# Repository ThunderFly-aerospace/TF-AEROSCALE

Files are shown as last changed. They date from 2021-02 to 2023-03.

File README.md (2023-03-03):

# TF-AEROSCALE
**Force balance for measuring lift and drag of aerodynamic surfaces**

Knowledge of aircraft wings is important for optimizing their flight parameters. This scale-type device is used to measure the polar of the wing or rotor. The device is designed so that it is possible to measure wings/rotors of various sizes. Because it is difficult to obtain a enought large wind tunnel, weight is designed so that it can be operated, for example, on the roof of a [TF-R1 driving car](https://github.com/ThunderFly-aerospace/TF-R1) that ensures suficiently high quality laminar flow.

## Features

* Robust construction to measure Lift and Drag forces up to 400 N.
* Open-source design (Open-source HW and SW)
* Scalability for different needs (OpenSCAD parametric design)
* Polar measurement capable (Lift and drag ratio calculation)
* Airspeed and groundspeed measurement
* RPM measurement (In case of rotor)
* Use on a car roof or in a wind tunnel

## Parameters

| Parameter | Value | Description |
|---|---|---|
| Sensing element | strain gauges |  |
| Interface | USB | The data readout is realised by direct control of I2C devices |
| Operating and storage temperature | -20 - +40°C |  |
| Operational humidity | 0-100 % | At humidity above 80% the performance of the sensors could be degraded in case of prolonged time periods |
| Input power | USB powered | |
| Mass | 5 kg |  |
| Dimensions |  600 x 560 x 600 mm| Height x width x lenght |
| Weather resistance | IP40 | |

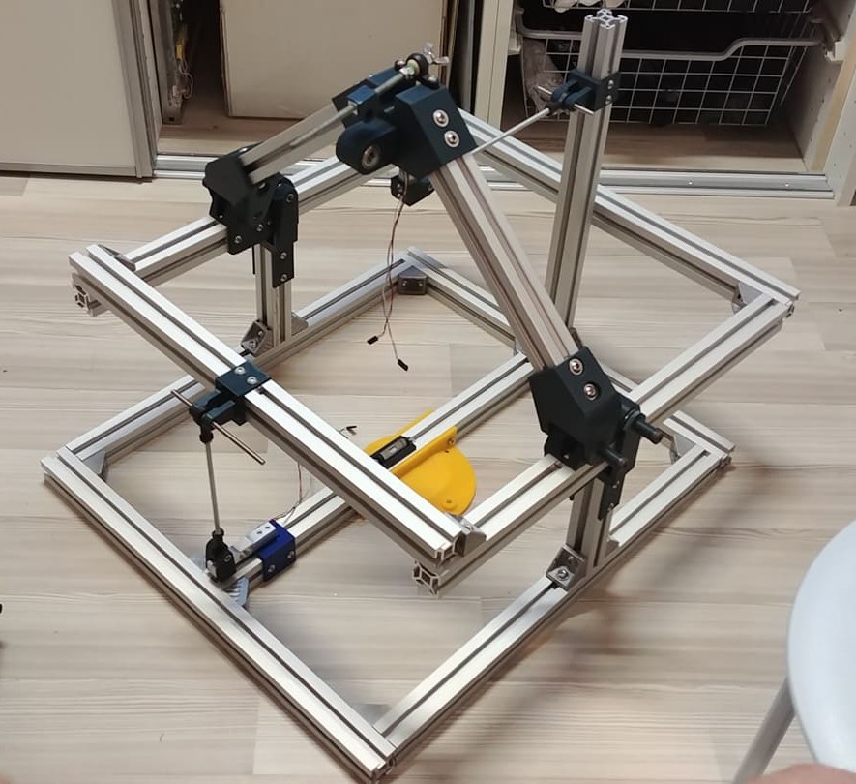
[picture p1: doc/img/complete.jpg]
Base with strain gauges


# Software installation

Repository use git submodules therefore an initialization of repository is needed prior make.

    git submodule init
    git submodule update

After that commands the make should be run from src directory.

    force_balance/cad/src$ make -j 4

## Electrical connection

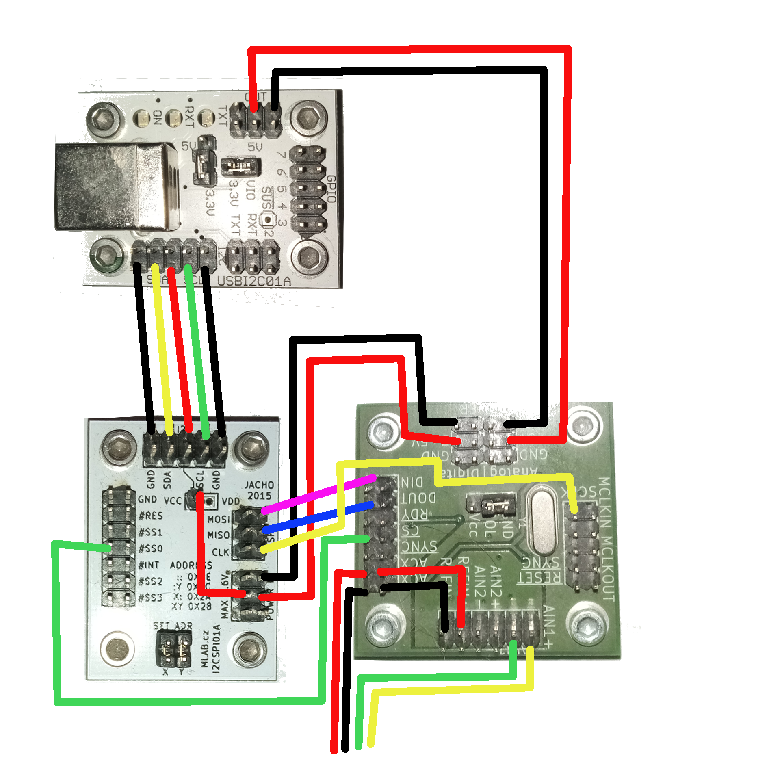
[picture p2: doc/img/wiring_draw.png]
Elecrical connection


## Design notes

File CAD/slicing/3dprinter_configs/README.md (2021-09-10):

# 3dprinter_configs

3D Printer configurations repository 

### Struktura

Ve složce src jsou dílčí zdrojové kódy konfigurací tiskáren. 

Složka `dist/<tiskarna>` obsahuje celkové ini soubory přímo pro užití se slicerem.

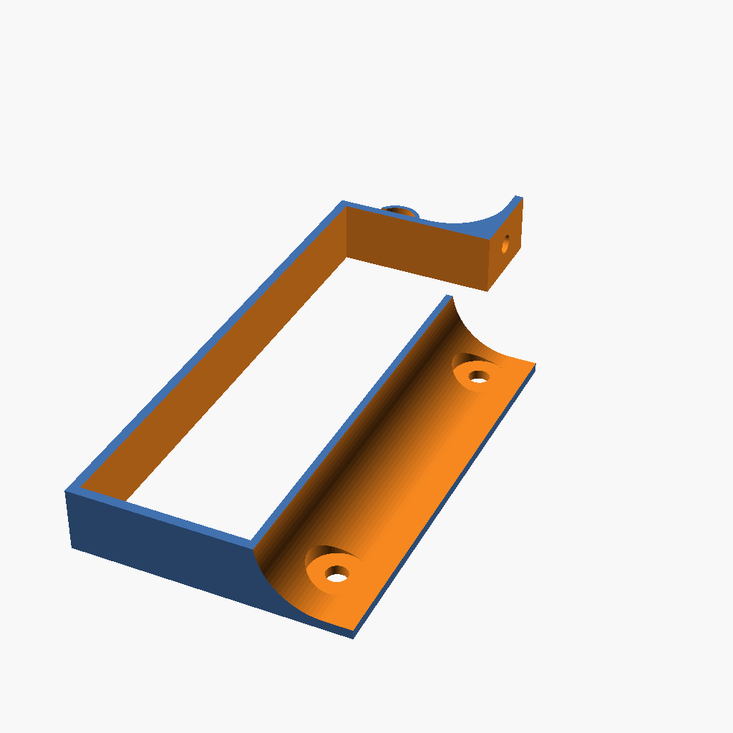
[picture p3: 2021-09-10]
CAD/png/888_5014_Back.png

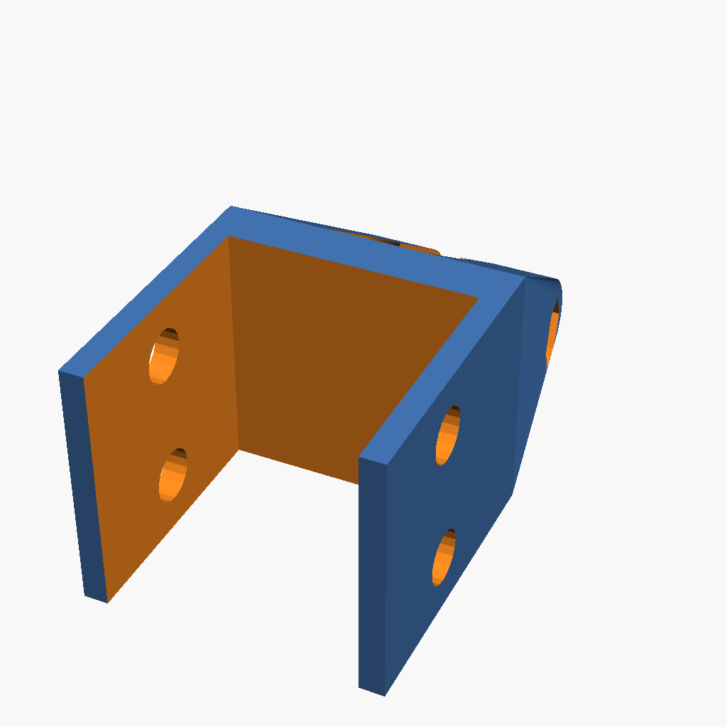
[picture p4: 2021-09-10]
CAD/png/888_5003_A.png

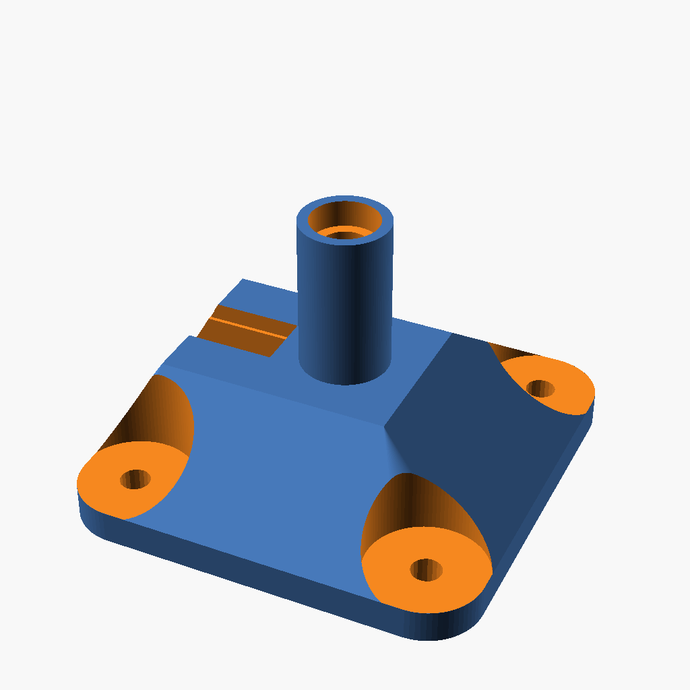
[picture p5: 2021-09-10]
CAD/png/TF_G2_rotor_adapter.png

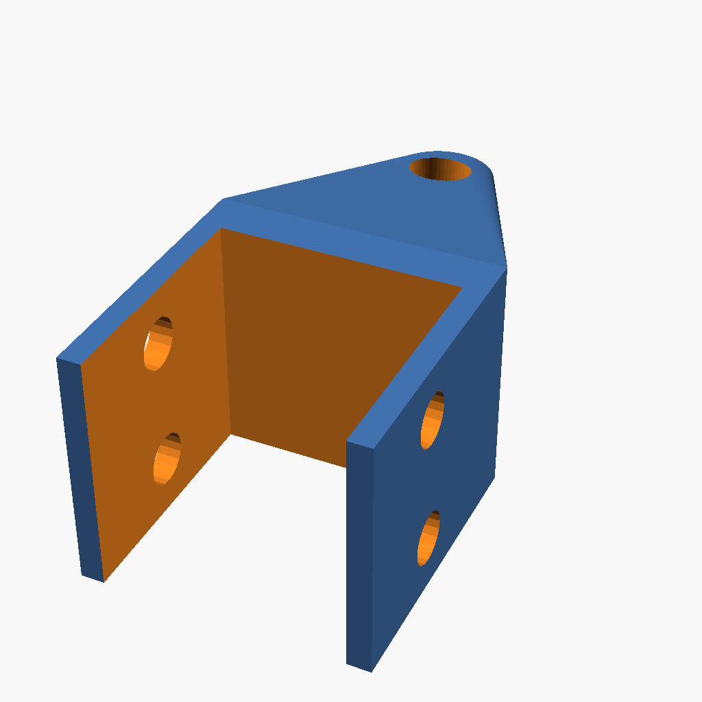
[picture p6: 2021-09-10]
CAD/png/888_5003_B.png

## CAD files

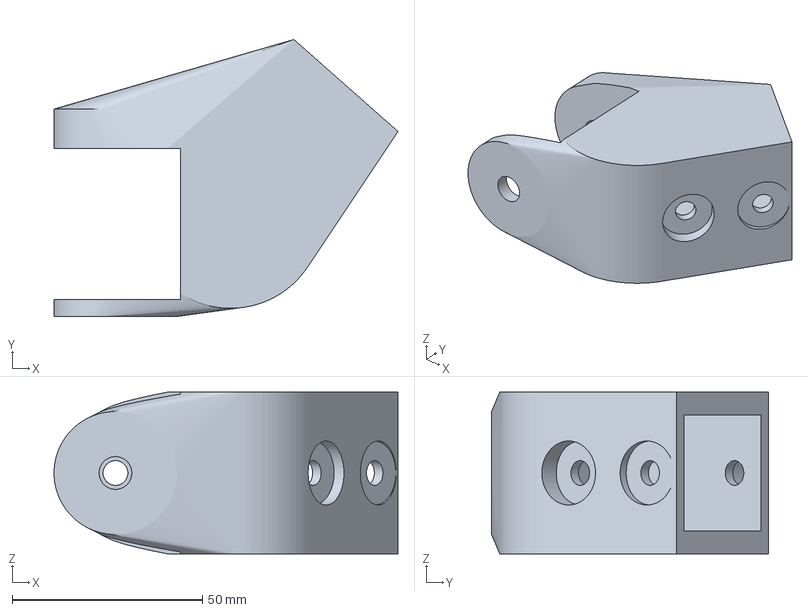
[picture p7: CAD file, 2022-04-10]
CAD/amf/888_5006.amf
90.4 x 72.8 x 42.5 mm

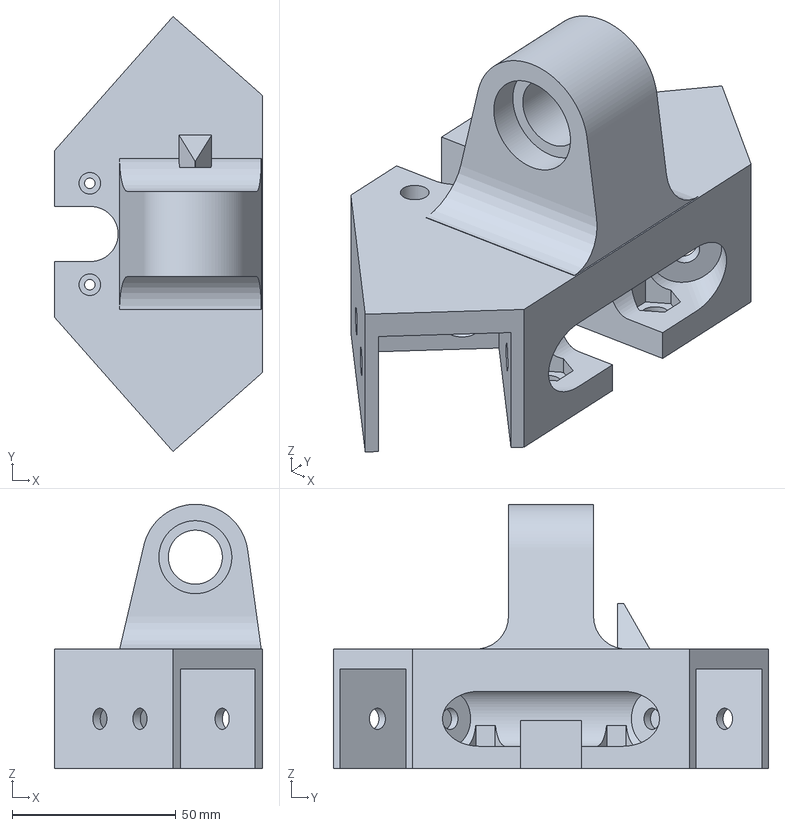
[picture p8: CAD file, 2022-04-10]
CAD/amf/888_5007.amf
63.6 x 132.9 x 80.8 mm

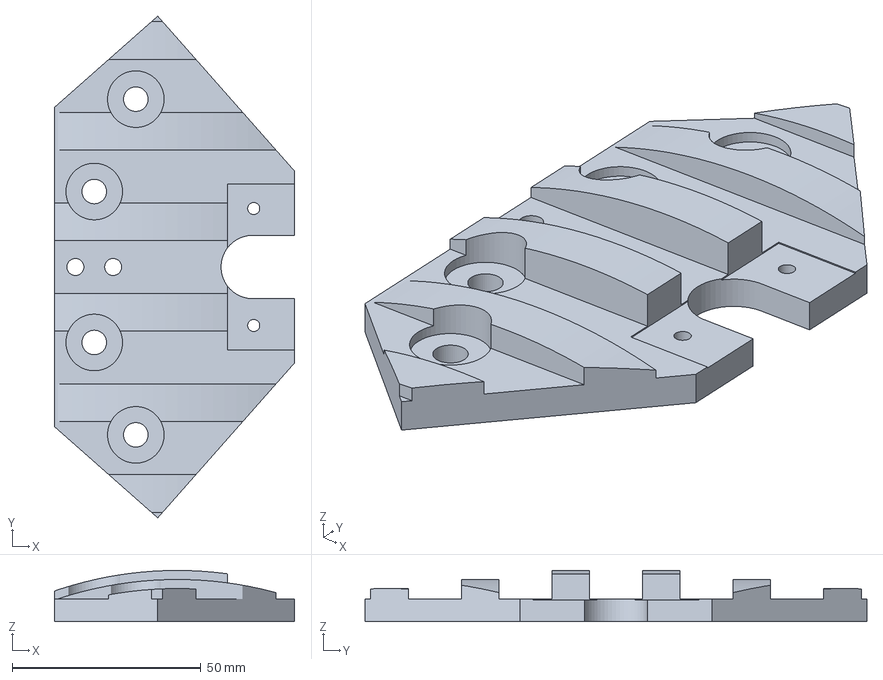
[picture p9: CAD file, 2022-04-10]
CAD/amf/888_5015.amf
63.6 x 132.9 x 13.6 mm

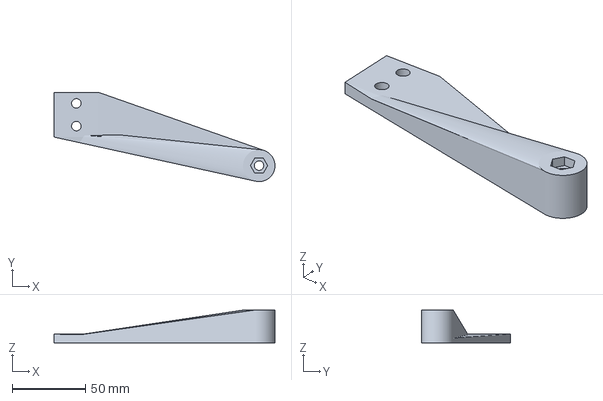
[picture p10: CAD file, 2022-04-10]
CAD/amf/888_1001.amf
150.9 x 60.9 x 22.4 mm

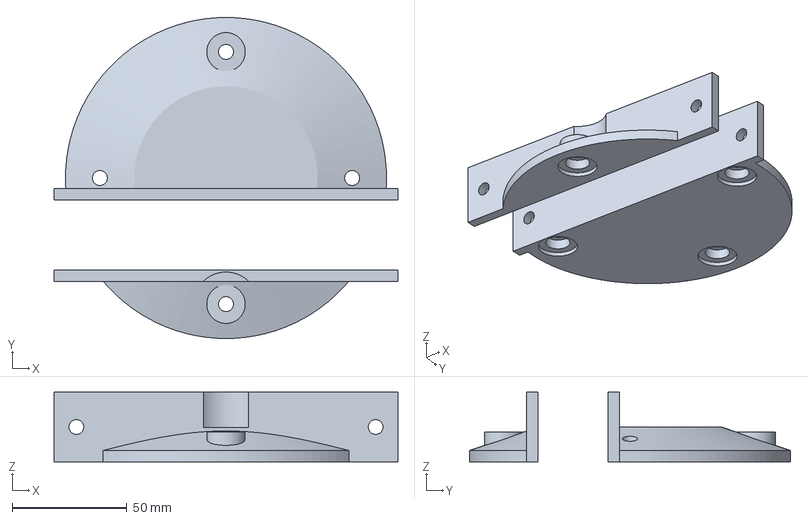
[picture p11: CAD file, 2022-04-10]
CAD/amf/888_3007.amf
150.0 x 140.0 x 30.5 mm

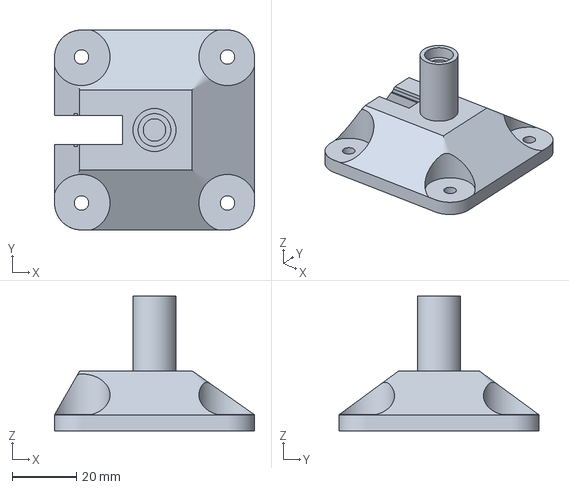
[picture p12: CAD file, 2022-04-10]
CAD/amf/TF_G2_rotor_adapter.amf
62.3 x 62.3 x 41.9 mm

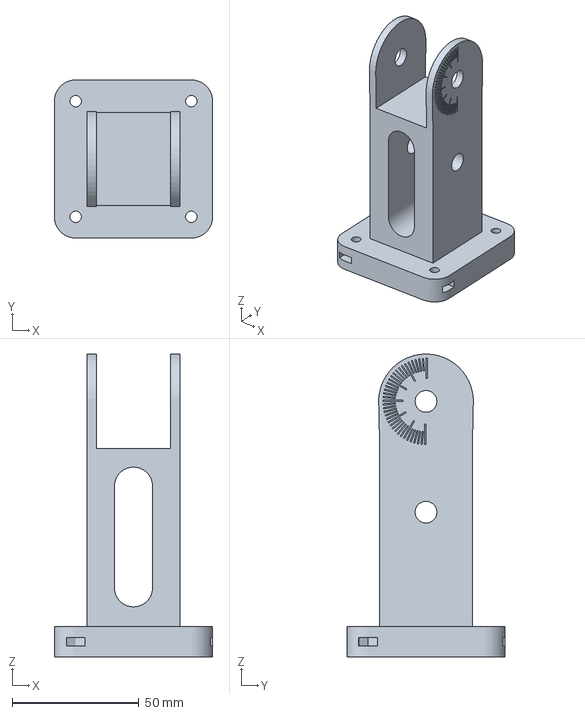
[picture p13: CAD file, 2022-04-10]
CAD/amf/888_5008.amf
62.3 x 62.3 x 119.3 mm

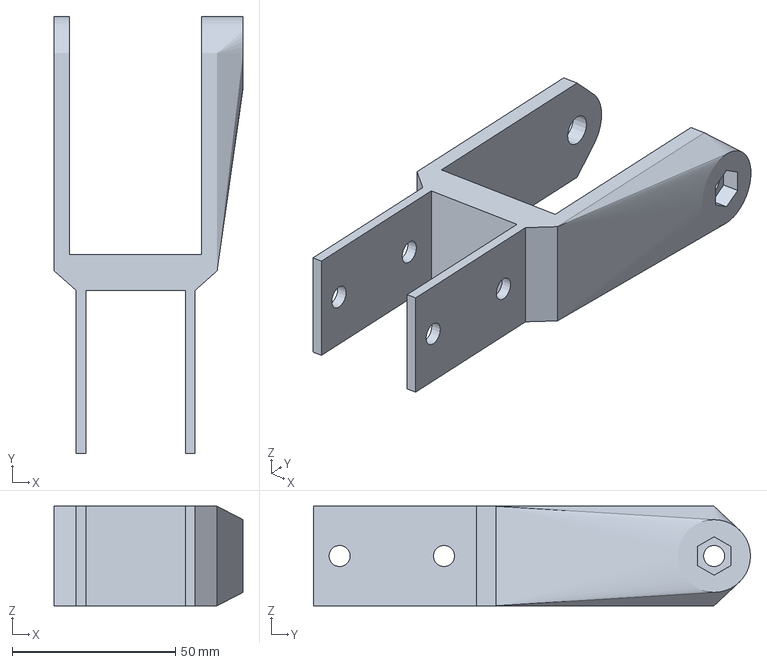
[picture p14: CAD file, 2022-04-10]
CAD/amf/888_5004.amf
57.9 x 133.9 x 30.5 mm

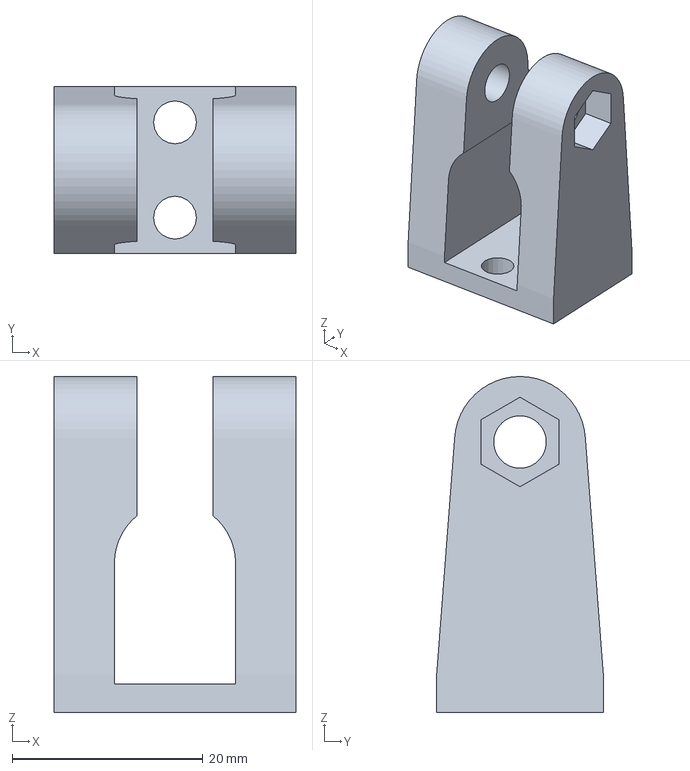
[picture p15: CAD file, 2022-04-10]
CAD/amf/888_5002.amf
25.4 x 17.5 x 35.3 mm

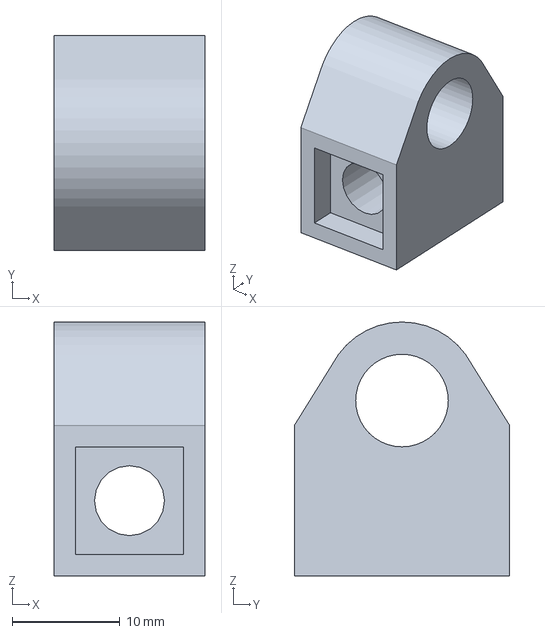
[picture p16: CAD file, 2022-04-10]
CAD/amf/888_5009.amf
14.0 x 20.0 x 23.6 mm

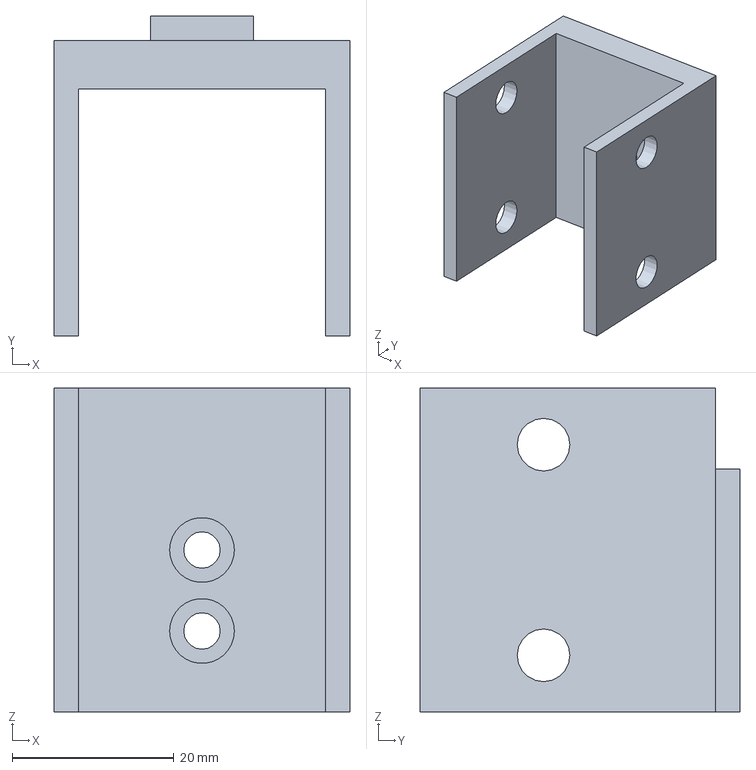
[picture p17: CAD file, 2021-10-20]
CAD/amf/888_5001.amf
36.5 x 39.5 x 40.0 mm

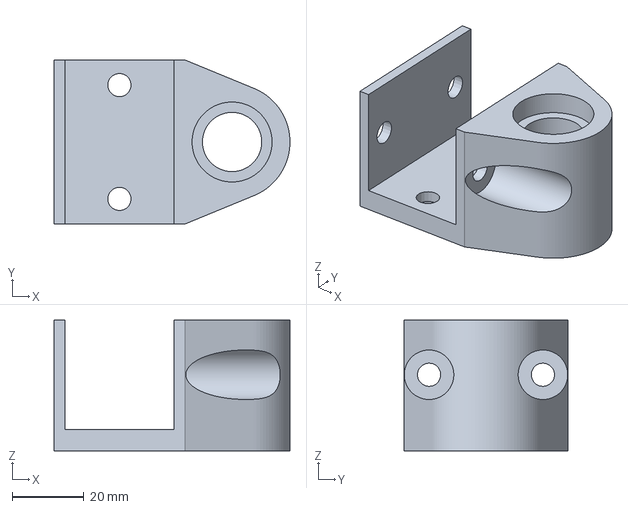
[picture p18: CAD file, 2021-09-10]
CAD/amf/888_5005.amf
65.8 x 45.8 x 36.5 mm

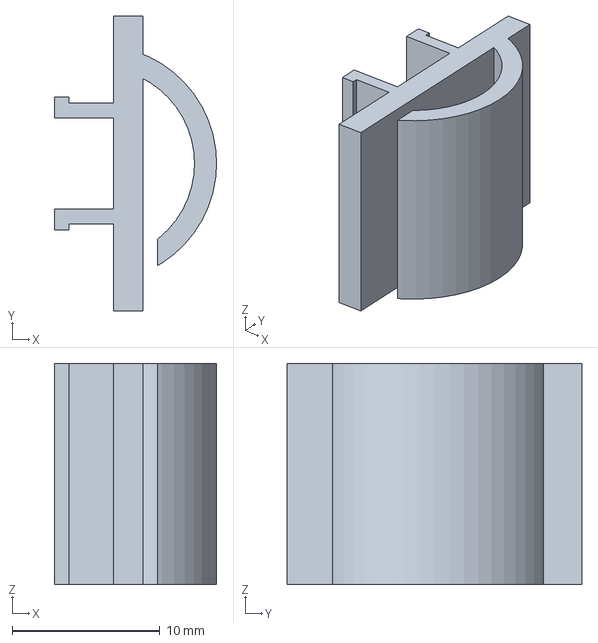
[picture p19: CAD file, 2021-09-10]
CAD/amf/888_5013.amf
11.0 x 20.0 x 15.0 mm

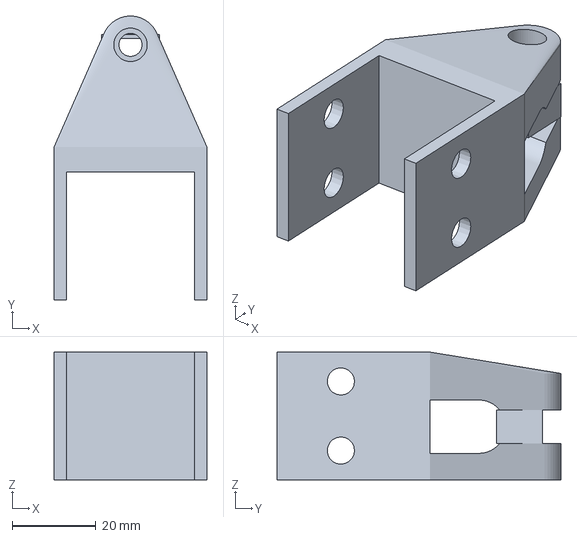
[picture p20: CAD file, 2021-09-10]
CAD/amf/888_5003_B.amf
36.5 x 67.8 x 30.5 mm

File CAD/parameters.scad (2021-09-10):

maximum_printable_size = 150;

layer_thickness = 0.3;
global_clearance = 0.5;


//Screw diameter and nut for M10 [mm]
M10_screw_diameter = 10.4;
M10_head_height = 10;
M10_head_diameter = 16+0.5;
M10_nut_height = 10.5;
M10_nut_diameter = 25.5;
M10_nut_pocket = 22.3;

//Screw diameter for M8 [mm]
M8_screw_diameter = 8.6;
M8_head_height = 8;
M8_head_diameter = 13.5;
M8_nut_height = 7.5;
M8_square_nut_thin_height = 4.5;
M8_nut_diameter = 14.4 + 0.5;
M8_nut_pocket = 13 + 0.5;
M8_washer_diameter = 16;
M8_washer_thickness = 1.5;


//Screw diameter and nut for M6 [mm]
M6_screw_diameter=6.5;
M6_head_diameter = 10+0.5;
M6_head_height = 6;
M6_nut_height = 4.9;
M6_nut_diameter = 11.8;
M6_nut_pocket = 10.4;
M6_square_nut_height = 3;
M6_square_nut_diameter = 10;
M6_washer_thickness = 1.6;

//Screw diameter and nut for M5 [mm]
M5_screw_diameter=5.5;
M5_head_height = 5;
M5_head_diameter = 13+0.5;
M5_nut_height = 4.5;
M5_nut_diameter = 9.4;
M5_nut_pocket = 8.4;

//Screw diameter and nut for M4 [mm]
M4_screw_diameter=4.5;
M4_screw_head_height = 4;
M4_nut_height = 3.2;
M4_nut_diameter = 8.4;
M4_nut_pocket = 7.5;

//Screw diameter and nut for M3 [mm]
M3_screw_diameter = 3.2;
M3_nut_height = 2.7;
M3_nut_diameter = 6.6;
M3_nut_pocket = 5.6;
M3_screw_head_height = 3;

//Screw diameter and nut for M2,5 [mm]
M2_5_screw_diameter = 2.7;
M2_5_nut_height = 2.3;
M2_5_nut_diameter = 6;
M2_5_nut_pocket = 5.5;

// kulove lozisko

bearing_efsm_08_h = 33+1;
bearing_efsm_08_m = 22;
bearing_efsm_08_db = 18;
bearing_efsm_08_ag = 10.5;
bearing_efsm_08_n = M4_screw_diameter;
bearing_efsm_08_a1 = 5.5;
bearing_efsm_08_d = 8.25;
bearing_efsm_08_B = 8; // ball height

bearing_efsm_10_h = 38+1;
bearing_efsm_10_m = 26;
bearing_efsm_10_db = 21.9;
bearing_efsm_10_ag = 12+0.2;
bearing_efsm_10_n = M5_screw_diameter;
bearing_efsm_10_a1 = 6.5;
bearing_efsm_10_d = 10.25;


bearing_efsm_12_width = 40+1;
bearing_efsm_12_h = bearing_efsm_12_width;
bearing_efsm_12_boltd = 28/2; // polovina vzdalenosti mezi srouby
bearing_efsm_12_m = bearing_efsm_12_boltd*2;
bearing_efsm_12_db = 25;
bearing_efsm_12_ag = 13;
bearing_efsm_12_a1 = 7;
bearing_efsm_12_n = M5_screw_diameter;
bearing_efsm_12_d = 12.15;
bearing_efsm_12_B = 10; // ball height
bearing_efsm_space = 1;

bearing_efsm_17_width = 54+1;
bearing_efsm_17_h = bearing_efsm_17_width;
bearing_efsm_17_boltd = 38/2; // polovina vzdalenosti mezi srouby
bearing_efsm_17_m = bearing_efsm_17_boltd*2;
bearing_efsm_17_db = 35;
bearing_efsm_17_ag = 18;
bearing_efsm_17_n = M6_screw_diameter;
bearing_efsm_17_a1 = 10;
bearing_efsm_17_B = 17; // ball height

//limcove lozisko
bearing_EFOM_10_L=26; //celkova sirka zakladny
bearing_EFOM_10_d1=10.3;//diametr otvoru real=10 mm
bearing_EFOM_10_dB=22;//diametr vystupku pro ulozeni lozika
bearing_EFOM_10_H=52;//celková delka zakladny
bearing_EFOM_10_J=36;// hole pitch
bearing_EFOM_10_A1=6.5;//vyska pouzdra
bearing_EFOM_10_Ag=12;//celkova vyska
bearing_EFOM_10_N1=5;//sirka otvoru pro sroub
bearing_EFOM_10_N2=8;//delka otvoru pro sroub
bearing_EFOM_10_m=36;//roztec der pro sroub
bearing_EFOM_10_h=9;//vyska lozika


608_bearing_outer_diameter = 22.3;
608_bearing_inner_diameter = 16;
608_bearing_thickness = 7.1;


// 20 KG servo parameters

servo_20kg_axis_offset = 9.375; // jak je osa mimo stredu
servo_20kg_body_x = 42;
servo_20kg_body_y = 21;
servo_20kg_body_z = 40;
servo_20kg_thread_x = 49/2;
servo_20kg_thread_y = 10/2;
servo_20kg_body_below = 10; // jak hluboko je tělo serva pod drzaky na srouby
servo_20kg_below = 25.8; // jak hluboko je páka serva pod drzaky na srouby

servo_20kg_bolt_d = 2.5+0.3;
servo_20kg_nut_d = 5+0.3;


//strain gauge
strain_gauge_width = 12.7;
strain_gauge_length = 75.1;
strain_gauge_screw_distance = 10;

//ALU profile
ALU_profile_width = 30.5;
ALU_profile_holder_wall_thickness = 3;
ALU_profile_groove_width = 8;

//pillow block bearing
//https://www.igus.eu/product/372
//Part no. KSTM-08
KSTM08_screws_distance = 33;         //m
KSTM08_screws_holes_diameter = 4.5;  //d2
KSTM08_flange_thickness = 6;         //h3
KSTM08_case_width = 9;               //C1
KSTM08_case_length = 47;             //a
KSTM08_ball_width = 12;              //B
KSTM08_ball_hole_diameter = 7.85;    //d1


//ložiska pro malý rotor
bearing_outer_diameter = 10.2;    // Rozměr B1 v nákresu s přídavkem na toleranci otvoru
bearing_thickness = 4;        // Rozměr B2 v nákresu
//bearing_shaft_length = 19.5;    // Rozměr B3 v nákresu, Originalni hodnota 19.5
bearing_shaft_length = 20;    // Rozměr B3 v nákresu


//parametry víčka s telemetrickou anténou
S01_sila_materialu=1.2;
S01_vyska_horni_zavit=10;
S01_hloubka_zavitu=4;
S01_prumer_vnitrni=50;
LO_spodni_prumer=17.2;
LO_vyska_bez_krytu=15;
S01_tolerance_zavit=1.5;
R01_vyska_prekryti_statoru=10;

g3_0_cone1 = 70;
g3_0_srcew_dist = 55;



// scale parameters
base_length = 500;
mid_base_width = 500;
mid_base_height = 200;
mid_base_length = 500;
mid_base_x_offset = 50;
base_mid_base_hinge_offset = 50;
tower_height = 185;
tower_angle = atan((mid_base_width/2-ALU_profile_width-10)/tower_height);
tower_arm_length = tower_height/cos(tower_angle);
tower_drag_z_offset = 22;
electro_box_length = 225;
electro_box_width = 165;
electro_box_height = 51.5;

// calibration device parameters
calibration_arm_x_offset = 140;
calibration_arm_y_offset = 50;

// rotor paramters
rotor_blades_count = 2;
rotor_delta_angle = 12;
blade_mount_screw = M3_screw_diameter;
blade_mount_nut = M3_nut_diameter;

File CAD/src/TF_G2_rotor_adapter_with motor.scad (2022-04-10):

include <../parameters.scad>

use <./TF-G2-rotor-neck.scad>

$fn = 100;


connector_hole_w=45;
connector_hole_d=4.2;
connector_h=5;

connector_top_w=25;
connector_top_h=6;



TFPROBE01_PCB_thickness = 1.8;
TFPROBE01_PCB_width = 10.2;
TFPROBE01_sensor_height = 1.1;


motor_distance = -78.8; // vzdalenost prerotatoru od hlavni pos_y
motor_diameter = 35+2;
motor_axis_diameter = 6.3;
motor_puller_diameter = 20;
motor_screw_diameter = M3_screw_diameter;
motor_mounting_diameter = 25; // vzdalenost protejsich sroubu pro pridelani prerotatoru
motor_sink = 9.5+4+1; // pro zapusteni bez podlozek na motoru...


screw_offset=rotorBearingNeck_screw_offset();
screw_angle=rotorBearingNeck_screw_angle();

module TF_G2_rotor_adapter(){

    difference()
    {
        union()
        {        
            hull()
            {

                //podstava
                minkowski()
                {
                    translate([0,0,connector_h/2-motor_sink])
                        cube([connector_hole_w,connector_hole_w,0.001],center=true);
                    cylinder(d=16,h=connector_h,center=true);
                }                 
                
                //zamek
                translate([0,0,-connector_top_h/2])
                    cube([connector_top_w,connector_top_w,connector_top_h],center=true);
                
                //motor
                translate([0,motor_distance,-motor_sink/2])
                    cylinder(d=motor_diameter,h=motor_sink,center=true);
                    
                //rpm
                translate([0,5+rotorBearingNeck_t()/2+2,-TFPROBE01_sensor_height-TFPROBE01_PCB_thickness/2])
                   cube([TFPROBE01_PCB_width+2,10,TFPROBE01_PCB_thickness+2], center=true);
            }
        }
        
        //zámek krčku
        rotorBearingNeckHousing();
       
        //šrouby motoru        
        translate([0,motor_distance,0])
            rotate([0,0,45])
            {
                cylinder(d=motor_puller_diameter, h=5*motor_sink,center=true);
                for(i=[-1,1])
                    translate([i*motor_mounting_diameter/2,0,0])
                    {
                       cylinder(d=motor_screw_diameter,h=5*motor_sink,center=true);
                       translate([0,0,-3])
                            cylinder(d=5.5,h=3.01);
                    }
                for(i=[-1,1])
                    translate([0,i*motor_mounting_diameter/2,0])
                    {
                       cylinder(d=motor_screw_diameter,h=5*motor_sink,center=true);
                       translate([0,0,-3])
                            cylinder(d=5.5,h=3.01);
                    }
            }
        
        //odlehčení
        hull()
        {
            translate([0,-30,0])
                cylinder(d=22,h=5*motor_sink, center=true);
                
            translate([0,-62,0])
                cube([28,1,5*motor_sink], center=true);
        
        }
        
        //rpm senzor
        translate([0,50/2+rotorBearingNeck_t()/2-2,-2.5*motor_sink-TFPROBE01_sensor_height])
           cube([TFPROBE01_PCB_width-2,50,5*motor_sink], center=true);
        translate([0,50/2+rotorBearingNeck_t()/2-2,+2.5*motor_sink-TFPROBE01_sensor_height+0.2])
           cube([TFPROBE01_PCB_width-2,50,5*motor_sink], center=true);
        translate([0,50/2+rotorBearingNeck_t()/2-2,-TFPROBE01_sensor_height-TFPROBE01_PCB_thickness/2])
           cube([TFPROBE01_PCB_width,50,TFPROBE01_PCB_thickness], center=true);
        
        //šrouby
        for(i=[-1,1])
            for(j=[-1,1])
            {
                translate([i*connector_hole_w/2,j*connector_hole_w/2,0])
                {
                    cylinder(d=connector_hole_d,h=5*motor_sink,center=true);
                    translate([0,0,-motor_sink+connector_h])
                        cylinder(d=16,h=5*motor_sink);
                }
            }
            
            
        //matice    
        for(i=[-1,1])  
        translate([i*(screw_offset),-screw_offset,0])
            rotate([screw_angle,0,0])
                translate([0,0,-7-M3_nut_height])
                hull()
                {
                    cylinder(d=M3_nut_pocket+0.9,h=M3_nut_height+0.1, $fn=6);
                    translate([i*50,0,0])
                        cylinder(d=M3_nut_pocket+0.9,h=M3_nut_height+0.1, $fn=6);
                }
        //díra pro štělování ložiska
        cylinder(d=3.5,h=50, center=true);
    }
    
    //vyztuha na vršku matice
    for(i=[-1,1])  
    translate([i*(screw_offset),-screw_offset,0])
        rotate([screw_angle,0,0])
            translate([0,0,-7+0.1])
                cylinder(d=7,h=0.2, $fn=6);

    
    
}


TF_G2_rotor_adapter();

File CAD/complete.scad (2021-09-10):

include <./parameters.scad>
use <./src/lib/ALU_profile.scad>
use <./src/888_3007.scad>
use <./src/888_5001.scad>
use <./src/888_5002.scad>
use <./src/888_5003.scad>
use <./src/888_5004.scad>
use <./src/888_5005.scad>
use <./src/888_5006.scad>
use <./src/888_5007.scad>
use <./src/888_5008.scad>
use <./src/888_5009.scad>
use <./src/888_5010.scad>
use <./src/888_5011.scad>
use <./src/888_5012.scad>
use <./src/888_5013.scad>
use <./src/888_5014.scad>
use <./src/888_5015.scad>
use <./src/888_1001.scad>
use <./src/888_1002.scad>
use <./src/888_1003.scad>


base_width = mid_base_width+ALU_profile_width*2+ALU_profile_holder_wall_thickness*2+M6_washer_thickness*2;
side_pillars_offset = -ALU_profile_width/2+base_mid_base_hinge_offset;
mid_base_height_offset = (608_bearing_outer_diameter+10)/2-1;

module tenzometer(mounting_part=true) {
    translate([-strain_gauge_length/2, -strain_gauge_width/2, 0])
    color([0, 0, 1])
    cube([strain_gauge_length, strain_gauge_width, strain_gauge_width]);
    
    if(mounting_part) {
        translate([-7.5, ALU_profile_width/2+ALU_profile_holder_wall_thickness, -ALU_profile_holder_wall_thickness])
        rotate([90, 0 ,-90])
        color([0, 1, 1])
        888_5001();
    }
    
    translate([strain_gauge_length/2-(strain_gauge_screw_distance*1.75)/2, 0, 0])
    rotate([0, 0 ,90])
    color([0, 1, 1])
    888_5002();
}


// base ///////////////////////////////////////////////////////////////
translate([-base_length/2, 0, ALU_profile_width/2])
rotate([0, 90, 0])
ALU_profile(height=base_length);

translate([-base_length/2, base_width/2-ALU_profile_width*2+ALU_profile_holder_wall_thickness+5, ALU_profile_width/2])
rotate([0, 90, 0])
ALU_profile(height=base_length);

translate([-base_length/2, -base_width/2+ALU_profile_width*2-ALU_profile_holder_wall_thickness-5, ALU_profile_width/2])
rotate([0, 90, 0])
ALU_profile(height=base_length);

translate([-base_length/2-ALU_profile_width/2, -base_length/2, ALU_profile_width/2])
rotate([0, 90, 90])
ALU_profile(height=base_length);

translate([base_length/2+ALU_profile_width/2, -base_length/2, ALU_profile_width/2])
rotate([0, 90, 90])
ALU_profile(height=base_length);

translate([mid_base_length/2-mid_base_x_offset+2, 0, ALU_profile_width+ALU_profile_holder_wall_thickness*3])
tenzometer();

// car attachment point
translate([0, 24.8, 0])
rotate([0, 0, 0])
color([0, 1, 1])
888_3007();

//box
translate([mid_base_length/2, -base_length/2+3, ALU_profile_width])
rotate([0, 0, 180])
color([0, 1, 1])
888_5014_back();

translate([mid_base_length/2-150, -base_length/2+3, ALU_profile_width])
rotate([0, 0, 180])
color([0, 1, 1])
888_5014_front();

translate([mid_base_length/2+ALU_profile_width/2, -base_length/2+3+electro_box_width+ALU_profile_width, ALU_profile_width+3])
rotate([0, 0, 180])
color([0, 1, 1])
#cube([electro_box_length, electro_box_width, electro_box_height]);

// front pillar //////////////////////////////////////////////////////
translate([-base_length/2-ALU_profile_width/2, 0, ALU_profile_width])
ALU_profile(height=mid_base_height+tower_height+20);

translate([-base_length/2+ALU_profile_holder_wall_thickness*2, -ALU_profile_width/2-ALU_profile_holder_wall_thickness, tower_height-strain_gauge_length/2-tower_drag_z_offset/2+2+mid_base_height+ALU_profile_width*2+ALU_profile_holder_wall_thickness*2-strain_gauge_length/2+(strain_gauge_screw_distance*1.75)/2+M5_screw_diameter*2.5/2])
rotate([180, 0, 90])
color([0, 1, 1])
888_5003_A();


// side pillars ///////////////////////////////////////////////////////
translate([-side_pillars_offset-ALU_profile_width/2, -base_width/2+ALU_profile_width*2-ALU_profile_holder_wall_thickness-5, ALU_profile_width])
ALU_profile(height=mid_base_height+mid_base_height_offset-ALU_profile_width*2-ALU_profile_holder_wall_thickness*4);

translate([-side_pillars_offset-ALU_profile_width/2, base_width/2-ALU_profile_width*2+ALU_profile_holder_wall_thickness+5, ALU_profile_width])
ALU_profile(height=mid_base_height+mid_base_height_offset-ALU_profile_width*2-ALU_profile_holder_wall_thickness*4);

// mid base hinges - static attachment points
translate([-side_pillars_offset, base_width/2-ALU_profile_width*2+ALU_profile_holder_wall_thickness+5, mid_base_height-mid_base_height_offset])
rotate([90, 0, -90])
color([0, 1, 1])
888_5004();

translate([-side_pillars_offset-ALU_profile_width, -base_width/2+ALU_profile_width*2-ALU_profile_holder_wall_thickness-5, mid_base_height-mid_base_height_offset])
rotate([90, 0 ,90])
color([0, 1, 1])
888_5004();

// mid base ///////////////////////////////////////////////////////////
translate([-mid_base_length/2-mid_base_x_offset, mid_base_width/2-ALU_profile_width/2, ALU_profile_width/2+mid_base_height])
rotate([0, 90, 0])
ALU_profile(height=mid_base_length);

translate([-mid_base_length/2-mid_base_x_offset, -mid_base_width/2+ALU_profile_width/2, ALU_profile_width/2+mid_base_height])
rotate([0, 90, 0])
ALU_profile(height=mid_base_length);

translate([-mid_base_length/2-ALU_profile_width/2-mid_base_x_offset, -mid_base_width/2, ALU_profile_width/2+mid_base_height])
rotate([0, 90, 90])
ALU_profile(height=mid_base_width);

translate([mid_base_length/2-ALU_profile_width/2-mid_base_x_offset, -mid_base_width/2, ALU_profile_width*1.5+mid_base_height])
rotate([0, 90, 90])
ALU_profile(height=mid_base_width);

// lift strain gauge attachment point    
translate([mid_base_length/2+ALU_profile_holder_wall_thickness*2-mid_base_x_offset, -ALU_profile_width/2+strain_gauge_width, mid_base_height-ALU_profile_holder_wall_thickness+ALU_profile_width])
rotate([-90, -90 ,0])
color([0, 1, 1])
888_5003_B();
    
// base hinges
translate([ALU_profile_width*.75-base_mid_base_hinge_offset, -mid_base_width/2+ALU_profile_width+ALU_profile_holder_wall_thickness*2, mid_base_height-ALU_profile_holder_wall_thickness])
rotate([0, -90 ,0])
color([0, 1, 1])
888_5005();
    
translate([-ALU_profile_width*.75-base_mid_base_hinge_offset, mid_base_width/2-ALU_profile_width-ALU_profile_holder_wall_thickness*2, mid_base_height-ALU_profile_holder_wall_thickness])
rotate([0, -90, 180])
color([0, 1, 1])
888_5005();

// tower hinges attachment points
translate([ALU_profile_width*.75, -mid_base_width/2+ALU_profile_width+ALU_profile_holder_wall_thickness*2, mid_base_height-ALU_profile_holder_wall_thickness])
rotate([0, -90 ,0])
color([0, 1, 1])
888_5005();
    
translate([-ALU_profile_width*.75, mid_base_width/2-ALU_profile_width-ALU_profile_holder_wall_thickness*2, mid_base_height-ALU_profile_holder_wall_thickness])
rotate([0, -90, 180])
color([0, 1, 1])
888_5005();


// tower ///////////////////////////////////////////////////////////////////
translate([0, mid_base_width/2-ALU_profile_width, ALU_profile_width+mid_base_height+35])
rotate([tower_angle, 0 ,0])
translate([0, ALU_profile_width/2 ,0])
ALU_profile(height=tower_arm_length);

translate([0, -mid_base_width/2+ALU_profile_width, ALU_profile_width+mid_base_height+35])
rotate([-tower_angle, 0 ,0])
translate([0, -ALU_profile_width/2 ,0])
ALU_profile(height=tower_arm_length);

// tower hinges
translate([0, 0, ALU_profile_width+mid_base_height])
color([0, 1, 1])
888_5006(side=-1);
    
translate([0, 0, ALU_profile_width+mid_base_height])
color([0, 1, 1])
888_5006(side=1);

// rotor joint mekanism
translate([0, 0, ALU_profile_width+mid_base_height+35])
rotate([0, 0, 0])
color([0, 1, 1])
888_5007();

translate([0, 0, ALU_profile_width+mid_base_height+35])
rotate([0, 0, 0])
color([0, 1, 1])
888_5015();
    
translate([(608_bearing_outer_diameter+10+ALU_profile_width)/2+ALU_profile_holder_wall_thickness+15, 0, 70+(608_bearing_outer_diameter+10+5)/2+tower_height+mid_base_height+35+ALU_profile_width-12])
rotate([180, 0, 90])
color([0, 1, 1])
888_5008(); 

translate([(608_bearing_outer_diameter+10+ALU_profile_width)/2+ALU_profile_holder_wall_thickness+5, -M6_square_nut_diameter/2-1, 70+(608_bearing_outer_diameter+10+5)/2+tower_height+mid_base_height+ALU_profile_width-6])
rotate([180, 0, 90])
color([0, 1, 1])
888_5009();

// drag strain gauge attachment point
translate([-ALU_profile_width/2-ALU_profile_holder_wall_thickness*2+strain_gauge_width+6, 0, tower_height-strain_gauge_length/2-tower_drag_z_offset/2+2+mid_base_height+ALU_profile_width*2+ALU_profile_holder_wall_thickness*2])
rotate([0, 90, 180])
tenzometer(mounting_part=false);

// calibration device
translate([-base_length/2, -ALU_profile_width/2, mid_base_height+tower_height+20])
rotate([0, 0, 180])
color([1, 1, 0])
union() {
    888_1001();
    
    translate([calibration_arm_x_offset, -.5, calibration_arm_y_offset])
    rotate([90, 0, 0])
    888_1002();
}

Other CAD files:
CAD/amf/888_5014_Front.amf
CAD/amf/888_5012.amf
CAD/amf/888_5014_Back.amf
CAD/amf/888_5010.amf
CAD/print_plates/888_1001.scad
CAD/amf/888_1002.amf
CAD/amf/888_1003.amf
CAD/amf/888_5003_A.amf
CAD/amf/888_5011.amf
CAD/print_plates/888_1002.scad
CAD/print_plates/888_1003.scad
CAD/print_plates/888_3007.scad
CAD/print_plates/888_5001.scad
CAD/print_plates/888_5002.scad
CAD/print_plates/888_5003_A.scad
CAD/print_plates/888_5003_B.scad
CAD/print_plates/888_5004.scad
CAD/print_plates/888_5005.scad
CAD/print_plates/888_5006.scad
CAD/print_plates/888_5007.scad
CAD/print_plates/888_5008.scad
CAD/print_plates/888_5009.scad
CAD/print_plates/888_5010.scad
CAD/print_plates/888_5011.scad
CAD/print_plates/888_5012.scad
CAD/print_plates/888_5013.scad
CAD/print_plates/888_5014_Back.scad
CAD/print_plates/888_5014_Front.scad
CAD/print_plates/888_5015.scad
CAD/print_plates/TF_G2_rotor_adapter.scad
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

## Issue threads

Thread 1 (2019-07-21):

Délky a tolerance šroubů

kaklik, 2019-07-21:
Je potřeba zkontrolovat, zda všechny použité šrouby jsou sehnatelné (tj, mají potřebný rozměr v násobku 5mm)

kaklik, 2019-08-19:
Tenhle problém se momentálně týká zřejmě jen nejdelšího šroubu kyvného spoje.  Kde by spoj chtělo rozšířit tak, aby využíval celou délku 70mm šroubu a unesl tak i větší rotor.

kaklik, 2021-03-07:
Toto issue se s novou konstrukcí stalo irelevantním.

Closed 2021-03-07.

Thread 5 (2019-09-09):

Do základny vytvořit otvor pro matky a podložky šroubů

roman-dvorak, 2019-09-09:
- [x] Vytvořit díry na podložku a matku
- [x] Umístit váhu excentricky

**1**
Do dílu 888_3007 udělat okolo děr pro šrouby pro připevnění na střechu otvor pro zapuštění matic, kterými jsou šrouby permanentně připevněny ke střeše.

https://github.com/ThunderFly-aerospace/force_balance/blob/master/cad/STL/888_3007.stl

Nejlépe to vyřešit stejně jako je to tady:
https://github.com/ThunderFly-aerospace/TF-R1/blob/master/CAD/STL/888_4004.stl
Odtud lze opsat rozměr podložky a celkové velikosti otvoru.

**2**
Další věc, co mne napadá je, umístit váhu mírně excentricky a využít i přední a zadní šroub. Při přemontovávání plaformy zabere docela dost času tyto dva šrouby vytočit. Už jen z důvodu, že je pro to potřeba nějaký nástroj - klíč.

Váhu by stačilo umístít o šířku hliníkových dílů na jednu stranu.

kaklik, 2019-09-30:
V otvorech pouze chybí zaslepené vyrstvy umožňující tisk mostu a tím kvalitnější a pevnější výtisk.

Closed 2019-09-29.

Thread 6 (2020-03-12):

chyba v návrhu dílu 888_5008

kaklik, 2020-03-12:
Následující díl při otevření v openscadu hlásí chybu "UI-WARNING: Object may not be a valid 2-manifold and may need repair! "
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

V důsledku toho vyrenderovaný objekt nelze kompletně vyslicovat jak z STL, tak ani z AMF

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

Closed 2021-02-28.

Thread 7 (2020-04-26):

Měření otáček rotoru během testu

kaklik, 2020-04-26:
Při měření rotoru na aerodynamické váze je potřeba měřit otáčky.

Měření otáček by bylo možné realizovat několika způsoby:

 * ~~hacknutím/rozluštěním komunikace [HiTec senzoru](https://hitecrcd.com/products/aircraft-radios-receivers-and-accessories/telemetry-systems-components/telemetry-components-/hts-orpm-optical-rpm-sensor/product) vyzkoušeno v [repozitáři orpm](https://github.com/ThunderFly-aerospace/orpm)~~
 * ~~Doplněním optického kotoučku a optozávory a použitím snímače [TFRPM01](https://github.com/ThunderFly-aerospace/TFRPM01)~~
 * ~~Přidáním magnetu a hallovy sondy v kombinaci s [TFRPM01](https://github.com/ThunderFly-aerospace/TFRPM01)~~
 * Montáží [TFPROBE](https://github.com/ThunderFly-aerospace/TFPROBE01) a připojením na [RTC03A](https://github.com/MLAB-project/Modules/tree/master/clock/RTC03A)

taury55, 2021-03-08:
Po debatě s @roman-dvorak jsem vyrozuměl, že měření otáček se bude zaznamenávat stejným způsobem jako během letu a měření proto bude součástí rotorové konstrukce a není potřeba jej přidávat do konstrukce váhy.

Data ze senzoru bude zaznaménavát hardware a software váhy nebo se pro to bude využívat některé externí zařízení?

kaklik, 2021-03-08:
Domnívám se že snímač otáček bude v aktuální implementaci realizovaný TFRPM senzorem připojeným na stejnou sběrnici I2C, jako budou připojené tenzometry.
Celkově by tak celé zařízení mělo momentálně končit jedním USB kabelem do palubního počítače v autě.
Je tedy pravda, že z hlediska váhy to příliš speciální úpravy nevyžaduje. Jen je potřeba [držák rotoru](https://github.com/ThunderFly-aerospace/force_balance/blob/master/cad/STL/888_5009.stl). Upravit tak, aby do něj šel vložit snímač [TFPROBE](https://github.com/ThunderFly-aerospace/TFPROBE01).  Podobně, jako je to vyřešené na [rotorové hlavě TF-G2](https://github.com/ThunderFly-aerospace/TF-G2/blob/4s/CAD/stl/printplate_888_1012.stl), kde je snímač [TFPROBE zasunut do drážky z boku](https://github.com/ThunderFly-aerospace/TF-G2/issues/64#issuecomment-761890227).

kaklik, 2021-04-27:
Současné měření s použitím TFPROBE a TFRPM v principu funguje. Jen je potřeba doladit mechanické nedokonalosti adaptéru rotoru a vylepšit kabeláž.
Vítek nakonec chce používat TFSLOT připojený do TFRPM, čímž se využije průchozí I2C sběrnice na TFRPM.

Closed 2021-04-27.

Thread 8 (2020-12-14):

Zjistit, jestli existuje example v Arduinu

roman-dvorak, 2020-12-14:
Bylo by dobré zjistit, jestli dneska existuje nějaký dostupný (arduino) example pro vyčítání převodníku, který obsahuje i interní kalibraci obvodem [AD7730l](https://www.analog.com/media/en/technical-documentation/data-sheets/AD7730_7730L.pdf)

Jedno z možných řešení je k ADpřevodníku připojit k arduino. Další možnost je přečíst si tento kód a implementovat to do pymlabu.

kaklik, 2021-03-07:
Vzhledem k aktuálnímu SW pokroku, který provedl @slimonslimon se toto issue stává irelevantním.

Closed 2021-03-07.

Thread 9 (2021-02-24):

Mechanical strengthening of the aerodynamic force balance

roman-dvorak, 2021-02-24:
Aktuální konstrukce váhy je velmi měkká. Má výrazné vůle do stran, což může způsobovat problémy nejen při měření. Váhu by bylo potřeba rozšířit tak, aby z této "2D" konstrukce se stala třírozměrná konstrukce, která bude v bočním směru pevná. Většina aktuálních dílů je moc pružná. Pokud budou znovu využity některé díly (např. držák tenzometru) tak by měl být zesílen.

Můj návrh je tedy následovný:
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

Díky tomu, že to není plochá konstrukce, tak z toho lze docela těžit u řešení jednotlivých kloubů, kdy se dost rozšiřují možnosti jejich umístění. Nákres není nakreslený v měřítku a jednotlivé délky pák by mělo jít nastavovat. Aktuálně jsou k dispozici dva roměry profilových tyčí (360 mm a 320 mm), které lze používat na první prototpy. Následně pak asi půjde získat jiné délky a tím optimalizovat poměry sil.

Bylo by užitečné aby k tomu existovala celková sestava, kde to bude vidět.

kaklik, 2021-03-07:
@taury55  vytvořil již kompletní celkovou sestavu nové konstrukce:

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

Closed 2021-03-07.

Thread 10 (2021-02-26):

Vibration measurements

roman-dvorak, 2021-02-26:
Bylo by vhodné vybavit vrchní část, kde bude připevňený rotor, měřením vibrací. Pro orientační měření by to mohlo být užitečné.

Toto by se dalo řešit zakomponováním TFSLOT pod rotor, kde by se zároveň s vibracemi měřil airspeed.

kaklik, 2021-02-26:
Nevim jestli je nutný ho připojovat přes SPI, možná by šlo vyčítat jen nějaké maximální a minimální hodnoty. Každopádně je logické ho na SPI připojit, protože tam stejně SPI musí být kvůli těm [BRIDGEADC](https://github.com/mlab-modules/BRIDGEADC01), které se používají pro připojení tenzometrů.

roman-dvorak, 2021-02-26:
Tak o to více by to chtělo získat ten USB-SPI převodník :)

roman-dvorak, 2021-02-26:
Jako extrémní využití tohoto měření bych si dokázal představit nějaké asistované vyvažování rotoru. Něco jako funguje vyvažování kol auta.

kaklik, 2021-02-27:
Jenže k tomu by tam kromě měření otáček muselo být i měření úvratě. Třeba asi tím magnetickým čidlem..
Výhoda by ale byla, že by tím šlo asi oddělit mechanický zdroj vibrací od těch aerodynamických.

roman-dvorak, 2021-02-27:
Připadá mi to jako stejný požadavek na měření polohy rotoru u mlýnku na
elektrické pole.

so 27. 2. 2021 v 12:52 odesílatel Jakub Kákona <notifications@github.com>
napsal:

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

kaklik, 2021-02-27:
Zdá se, že ten snímač, pro který máme v mlabu modul [RPS01A](https://github.com/MLAB-project/Modules/blob/master/sensors/RPS01A/doc/pdf/AS5048_Datasheet_EN_v4.pdf) umí vzorkovat 10kHz. Což by na rotor, který má frekvenci rotace okolo 20Hz zřejmě mohlo stačit. :)

Jde to navíc zjevně připojit jak na SPI tak i I²C.  Potíž ale je. že by bylo potřeba na hřídel rotoru namontovat magnet. Což by asi bylo vhodné aby vyzkoušel @kakl během konstrukce elektrostatického mlýnku.

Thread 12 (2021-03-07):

Konstrukce kloubů

kaklik, 2021-03-07:
Pokud budou klouby váhy realizovány dvojicí kuličkových ložisek, podobně jako tomu je v předešlé konstrukci. Tak je potřeba, aby tato dvě ložiska byla při dotažení šroubu vzájemně rozepřena válečkem.  Protože jinak když se dvě ložiska budou stahovat přímo k sobě, tak se skříží.

Týká se to zejména tohoto spoje:
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

Který musí mít středový otvor větší, aby se tam vešel vytištěný rozpírací váleček, rozpírající vnitřní otočné kroužky ložisek.

Celková délka kloubu by také měla počítat s tím že je k dispozici lícovaný šroub délky 70mm, viz předcházející obdobný problém v issue #1

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

Closed 2021-03-08.

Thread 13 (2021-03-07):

Vyvážení aerodynamické váhy

kaklik, 2021-03-07:
Při konstrukci aerodynamické váhy je potřeba myslet na fakt, že aerodynamická váha bude muset být před měřením staticky vyvážena.
Tj. po osazení měřeným rotorem bude potřeba vynulovat sílu působící na tenzometry. Zejména na tenzometr měřící vztlak. Tenzometr odporu bude při jízdě pravděpdobně víceméně jednosměrně zatížen.

Navrhoval bych to vyřešit tak, že spoj vztlakový tenzometr-váha bude rozebírací. Například šroubem s křídlovou matkou.  Po montáži měřeného tenzometru na váhu se rozebere tento spoj. Čímže bude možné s váhou vertikálně hýbat a vidět silové působení  na pohyblivý horizontální díl.

Na kratší stranu tohoto dílu bude pak nutné přidávat závaží do stavu, než dojde k vyvážení. Vzhledem k rozložení sil a délce pák v aktuální sestavě lze předpokládat, že tato přidaná hmotnost bude bohužel muset být poměrně velká v řádu kilogramů.
Je tak otázka jaký materiál pro vyvážení zvolíme?

kaklik, 2021-03-08:
Zajímavý nápad. Možná by protažení profilu nemuselo být ani tak dramatické, jak je zobrazeno na obrázku.  Případně by možná stačilo, že bude pohyblivý obdélníkový díl více protažen k přednímu tenzometru. Závaží by se tak dalo věšet přímo na profil ze spodní strany.

Jako závaží se nám docela osvědčili wolframové řezné destičky. Mají ale nevýhodu, že se podobně jako třeba olověné kuličky sypou, čímž se mění pozice vyvážení.

U dalekohledů se tenhle problém řeší tak, že se použije závaží o konstantní hmotnosti, případně pouze jen několik typů závaží a dalekohled se na montáži vyvažuje posouváním závaží po tyči. Na tyč se závaží zajišťuje utažením šroubu vedoucího skrz závaží.

Co si o tomto způsobu vyvažování myslíte ostatní  @roman-dvorak  @slimonslimon ?

slimonslimon, 2021-03-09:
toto koresponduje s představou, kterou jsem měl když jsi mi problém vyvážení připoměl.

kaklik, 2021-03-12:
Prohlížel jsem si současnou implementaci řešení:

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

A mám z toho dojem, že když bude to závaží takhle na tom jednom prodlouženém profilu, tak se to bude celé nepříjemně kroutit.  Nebylo by  lepší ty profily prodloužit oba a mezi ně dát další příčný profil, který by bylo možné posouvat i se závažím?

roman-dvorak, 2021-03-12:
Připadá mi, že obecně je tam použito zbytečně moc profilů různých délek. Ten horní čtverec/obdélník by klidně mohl být z profilů jedné délky. Stejné by se použily i pro základnu a svislou tyč pro měření odporu.

taury55, 2021-03-12:
Spodní základna je tvořena z 5 500mm profilů. Přední sloupek má 380mm v návrhu a v realu bude mít 390mm v rámci recyklace profilů staré váhy. Středová základna byla původně tvořena 300mm a 400mm profily, ale v rámci nové koncepce proti závaží by se mohli změnit na 500mm profily. Profil by se posunul dopředu a výsledná konstrukce by mohla vypadat takto:

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

kaklik, 2021-03-15:
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

Aktuální řešení  vypadá docela dobře :)  Jen možná hrozí, že se ten pohyblivý obdélník bude kroutit do vrtule. Tak jestli ještě nezvážit nějaké jeho možné budoucí vyztužení.
Mě napadá tam případně přidat ještě jeden příčník dopředu, který by to zároveň mohl částečně vyvážit.

kaklik, 2021-04-27:
Myslím že aktuální konstrukce je dostatečně tuhá, aby ke kroucení nedocházelo.

Closed 2021-04-27.

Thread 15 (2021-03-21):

Airspeed measurement on an aerodynamic weight

kaklik, 2021-03-21:
@roman-dvorak  navrhuje airspeed měřit na dvou místech.

1. Přímo na střeše měřícího auta - asi s použitím [WINDGAUGE03](https://github.com/mlab-modules/WINDGAUGE03)
2. Přímo na aerodynamické váze - zřejmě nějakou variantou [TFSLOT01](https://github.com/ThunderFly-aerospace/TFSLOT01), nebo [TFPIPE01](https://github.com/ThunderFly-aerospace/TFPIPE01)

S umístěním senzoru na aerodynamickou váhu vznikla komplikace, neboť s ním nebylo počítáno od začátku návrhu váhy. Možnost je buď snímač dát nahoru pod rotor na díl nad tenzometrem.

Na obrázku označeno červeným čtvercem:

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

roman-dvorak, 2021-03-29:
Aby mohlo fungovat #10 (měření vibrací) z dat z IMU TFASPDIMU, tak je potřeba, aby připevňení airspeed senzoru bylo co nejblíže rotoru.

kaklik, 2021-03-29:
> Aby mohlo fungovat #10 (měření vibrací) z dat z IMU TFASPDIMU, tak je potřeba, aby připevňení airspeed senzoru bylo co nejblíže rotoru.

Ten pokus s měřením vibrací bych asi nechal až na fázi, kdy to [TFASPDIMU](https://github.com/ThunderFly-aerospace/TFASPDIMU01) budem mít připojené na SPI. Do té doby si myslím, že v konstrukci té váhy vzniknout ještě další dosud neplánované změny.

Spíš jako možný problém toho měření airspeed vidím [tohle](https://github.com/ThunderFly-aerospace/TFASPDIMU01/issues/5). Kdy ten snímač při zvýšené délce vodičů, která zrovna tady je potřeba, nebude fungovat.

kaklik, 2021-04-30:
Zatím bude vyřešeno snímačem TFSLOT přilepeným oboustrannou páskou.

Closed 2021-04-30.

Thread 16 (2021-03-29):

Calibration device for weight calibration

roman-dvorak, 2021-03-29:
Kalibrační přípravek by měl umožňovat snadnou kalibraci váhy v obou osách.

Představoval bych si to tak, že bude nějaký sloupek (jeřáb) který bude mít samonosnou základnu a to se postaví k váze (nebo do její konstrukce). Asi by bylo vhodné to vždy nějak moct zaaretovat aby to vždy bylo ve stejné poloze. Následně se provede kalibrace jedné osy a následně druhé.

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

kaklik, 2021-05-06:
@taury55  tento problém vyřešil zatím jednoduchou kladkou namontovanou na vertikální sloupek  přední části váhy.

Vzhledem k nedostatečné tuhosti vytištěného řešení, kterou by šlo sice zlepšit použitím žeber, ale stejně bude pro vyšší hmotnosti slabá. Tak by asi bylo lepší kladku předsadit před váhu pomocí hliníkového profilu, stejně jako jsou realizovány ostatní části váhy.
Kladka by tak mohla držet na podstatně kratším a symetrickém 3D tištěném dílu, který by se nasunul na konec profilu přišroubovaného vodorovně na existující sloupek.

kaklik, 2021-06-23:
Kalibrační kladka přidaná na váhu funguje

Closed 2021-06-23.

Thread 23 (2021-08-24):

Zvýšení pevnosti dílu pro montáž rotoru

kaklik, 2021-08-24:
Při testech došlo k odlomení držáku rotoru.

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

Je potřeba navrhnout model se zaoblenější přechodovou hranou.

kaklik, 2021-08-24:
@taury55 Navrhl model s novou konstrukcí přechodu.

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

kaklik, 2021-08-24:
Díl ale nejde vytisknout zřejmě kvůli manifold chybě v openscadu.
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

slimonslimon, 2021-12-06:
V jakém je tohle stavu?

kaklik, 2021-12-06:
> V jakém je tohle stavu?

Myslím že je to vyřešený. Akorát jsme to od té doby netestovali.

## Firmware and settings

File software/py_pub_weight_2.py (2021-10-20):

#!/usr/bin/python3

#uncomment for debbug purposes
#import logging
#logging.basicConfig(level=logging.DEBUG) 

import sys
import time
import datetime
import threading
import os
import math

from BRIDGEADC01 import BRIDGEADC01
from spidevWraper import SpiWrapper

import rclpy
from rclpy.node import Node

from std_msgs.msg import Float32

"""
publish data from TF-AEROSCALE on SPIDEV as ROS2 node. 
"""

class MinimalPublisher(Node):

    def __init__(self):
        super().__init__('minimal_weight_publisher')
        self.publisher1 = self.create_publisher(Float32, 'weight_1', 10)
        self.publisher2 = self.create_publisher(Float32, 'weight_2', 10)
        self.spi0 = SPIWraper(0)
        self.spi1 = SPIWraper(1)

        #Weight scale configuration..
        self.scale1 = BRIDGEADC01(self.spi0,0,1)
        self.scale1.reset()
        freq=self.scale1.setFilterAC(200)
        sys.stdout.write("frekvence vyčítání: %4.2f;\n" %(freq))

        self.scale2 = BRIDGEADC01(self.spi1,1,1)
        self.scale2.reset()
        freq=self.scale2.setFilterAC(200)
        sys.stdout.write("frekvence vyčítání: %4.2f;\n" %(freq))
        sys.stdout.flush()

        f = open("2ScaleCalibration.txt","r")
        lines = f.readlines()
        f.close()

        vals=lines[0].split()
        self.scale1.setChannelOnly(0)
        self.scale1.setOffsetRegister(int(vals[0]))
        self.scale1.setFullScaleRegister(int(vals[1]))
        self.scale1.setUnitCalibrationGain(float(vals[2]))

        vals=lines[1].split()
        self.scale2.setChannelOnly(0)
        self.scale2.setOffsetRegister(int(vals[0]))
        self.scale2.setFullScaleRegister(int(vals[1]))
        self.scale2.setUnitCalibrationGain(float(vals[2]))

        self.scale1.startConntinuousConversion(0)
        self.scale2.startConntinuousConversion(0)

        self.timer = self.create_timer(0.001, self.timer_callback)
        self.w1d=False
        self.w2d=False
        self.w1=0.0
        self.w2=0.0
        self.lastTime=time.time()

    def timer_callback(self):
        if not self.w1d:
            self.w1d=not self.scale1.isBusy()
            if self.w1d:
               self.w1 = self.scale1.measureWeight()
        if not self.w2d:
            self.w2d=not self.scale2.isBusy()
            if self.w2d:
               self.w2 = self.scale2.measureWeight()

        if self.w1d and self.w2d:
            currentTime=time.time();
            ts = datetime.datetime.utcfromtimestamp(time.time()).isoformat()
            #sys.stdout.write("%s;  %04.1f;  %06.3f;  %06.3f;\n" %(ts, 1/(currentTime-self.lastTime), self.w1,self.w2))
            #sys.stdout.flush()
            self.lastTime=currentTime
            self.w1d=False
            self.w2d=False

            msg = Float32()
            msg.data = self.w1
            self.publisher1.publish(msg)

            msg2 = Float32()
            msg2.data = self.w2
            self.publisher2.publish(msg2)

def main(args=None):

    #sys.stdout.write("           system_datetime;  freq ;  scale1;  scale2;\n")
    #sys.stdout.flush()

    rclpy.init(args=args)
    minimal_publisher = MinimalPublisher()
    rclpy.spin(minimal_publisher)

    minimal_publisher.destroy_node()
    rclpy.shutdown()

if __name__=="__main__":
    main()

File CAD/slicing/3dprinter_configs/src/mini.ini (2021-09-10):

bed_shape = 0x0,180x0,180x180,0x180
bed_temperature = 60
;before_layer_gcode = ;BEFORE_LAYER_CHANGE\nG92 E0.0\n;[layer_z]\n\n
;HOTFIX, PrusaSlicer reset E(extruder) every change on layer, this dos not work for slic3r
before_layer_gcode = ;BEFORE_LAYER_CHANGE\n;[layer_z]\n\n
bridge_speed = 30
color_change_gcode = M600
compatible_printers_condition_cummulative = "printer_notes=~/.*PRINTER_VENDOR_PRUSA3D.*/ and printer_notes=~/.*PRINTER_MODEL_MINI.*/ and nozzle_diameter[0]==0.4";"nozzle_diameter[0]!=0.8 and ! (printer_notes=~/.*PRINTER_VENDOR_PRUSA3D.*/ and printer_notes=~/.*PRINTER_MODEL_MK(2.5|3).*/ and single_extruder_multi_material)"
;end_gcode = G1 E-1 F2100 ; retract\n{if max_layer_z < max_print_height}G1 Z{z_offset+min(max_layer_z+2, max_print_height)}{endif} F720 ; Move print head up\nG1 X178 Y178 F4200 ; park print head\n{if max_layer_z < max_print_height}G1 Z{z_offset+min(max_layer_z+30, max_print_height)}{endif} F720 ; Move print head further up\nG4 ; wait\nM104 S0 ; turn off temperature\nM140 S0 ; turn off heatbed\nM107 ; turn off fan\nM221 S100 ; reset flow\nM900 K0 ; reset LA\nM84 ; disable motors
; HOTFIX slic3r cannot calulate well level up, so combine relative approach
end_gcode = G1 E-1 F2100 ; retract\n; HOTFIX calculation level up, use relative\nG91 \n G1 Z5 F300\nG90\n G1 X178 Y178 F4200 ; park print head\nG4 ; wait\nM104 S0 ; turn off temperature\nM140 S0 ; turn off heatbed\nM107 ; turn off fan\nM221 S100 ; reset flow\nM900 K0 ; reset LA\nM84 ; disable motors
external_perimeter_speed = 30
first_layer_bed_temperature = 60
first_layer_speed = 20
gap_fill_speed = 40
infill_speed = 80
layer_gcode = ;AFTER_LAYER_CHANGE\n;[layer_z]
min_print_speed = 15
printer_notes = Don't remove the following keywords! These keywords are used in the "compatible printer" condition of the print and filament profiles to link the particular print and filament profiles to this printer profile.\nPRINTER_VENDOR_PRUSA3D\nPRINTER_MODEL_MINI\n; HOTFIX missing printer settings parameter in slic3r, append this after printer_notes:\nprinter_settings_id = Original Prusa MINI & MINI+
printer_settings_id = Original Prusa MINI & MINI+
retract_speed = 70
retract_length = 3.2
retract_before_travel = 3.2
small_perimeter_speed = 25
start_filament_gcode = "M900 K0.2 ; FIXME: prusa use multiple if parts, value is evaluated for MINI 0.4mm nooze\n; Filament gcode LA 1.0"
; HOTFIX: Missing part of Machine limits, let's use start_gcode
start_gcode = ;HOTFIX LIMITS START\nM73 P0 R28\nM201 X1250 Y1250 Z400 E5000 ; sets maximum accelerations, mm/sec^2\nM203 X180 Y180 Z12 E80 ; sets maximum feedrates, mm/sec\nM204 P1250 R1250 T1250 ; sets acceleration (P, T) and retract acceleration (R), mm/sec^2\nM205 X8.00 Y8.00 Z2.00 E10.00 ; sets the jerk limits, mm/sec\nM205 S0 T0 ; sets the minimum extruding and travel feed rate, mm/sec\nM107\n;HOTFIX LIMITS END\n;TYPE:Custom / original from PrusaCliser\nG90 ; use absolute coordinates\nM83 ; extruder relative mode\nM104 S170 ; set extruder temp for bed leveling\nM140 S[first_layer_bed_temperature] ; set bed temp\nM109 R170 ; wait for bed leveling temp\nM190 S[first_layer_bed_temperature] ; wait for bed temp\nG28 ; home all without mesh bed level\nG29 ; mesh bed leveling \nM104 S[first_layer_temperature] ; set extruder temp\nG92 E0.0\nG1 Y-2.0 X179 F2400\nG1 Z3 F720\nM109 S[first_layer_temperature] ; wait for extruder temp\n\n; intro line\nG1 X170 F1000\nG1 Z0.2 F720\nG1 X110.0 E8.0 F900\nG1 X40.0 E10.0 F700\nG92 E0.0\n\nM221 S95 ; set flow
support_material_interface_speed = 80%
has_heatbed = 1

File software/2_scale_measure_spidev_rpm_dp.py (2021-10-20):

#!/usr/bin/python3

#uncomment for debbug purposes
#import logging
#logging.basicConfig(level=logging.DEBUG) 

import sys
import time
import datetime
import threading
import os
import math
from pymlab import config

from BRIDGEADC01 import BRIDGEADC01
from spidevWraper import SpiWrapper

"""
Show data from TF-AEROSCALE over SPIDEV and I2C on rpi3. 
"""

#### Script Arguments ###############################################

if len(sys.argv) != 2:
    sys.stderr.write("Invalid number of arguments.\n")
    sys.stderr.write("Usage: %s angle\n" % (sys.argv[0], ))
    sys.exit(1)

i2cport  = 1
angle    = float(sys.argv[1])

#import numpy as np
#LOGGER = logging.getLogger(__name__)

cfg=config.Config(
        i2c = {
            "port": i2cport,
            "device": "smbus",
        },
        bus = [
            {
                "name":        "windgauge",
                "type":        "WINDGAUGE03A",
            },
            {
               "name": "rtc01",
               "type": "rtc01",
               "address": 0x50
            }
        ],
        )



spi0 = SPIWraper(0)
spi1 = SPIWraper(1)

#Weight scale configuration..
scale1 = BRIDGEADC01(spi0,0,1)
scale1.reset()
freq=scale1.setFilterAC(200)
sys.stdout.write("frekvence vyčítání: %4.2f;\n" %(freq))

scale2 = BRIDGEADC01(spi1,1,1)
scale2.reset()
freq=scale2.setFilterAC(200)
sys.stdout.write("frekvence vyčítání: %4.2f;\n" %(freq))
sys.stdout.flush()

f = open("2ScaleCalibration.txt","r")
lines = f.readlines()
f.close()

vals=lines[0].split()
scale1.setChannelOnly(0)
scale1.setOffsetRegister(int(vals[0]))
scale1.setFullScaleRegister(int(vals[1]))
scale1.setUnitCalibrationGain(float(vals[2]))

vals=lines[1].split()
scale2.setChannelOnly(0)
scale2.setOffsetRegister(int(vals[0]))
scale2.setFullScaleRegister(int(vals[1]))
scale2.setUnitCalibrationGain(float(vals[2]))

#RPM reading
counter = cfg.get_device("rtc01")
counter.set_config(counter.FUNCT_MODE_count)
counter.reset_counter()
signalPerRound=16
time.sleep(0.1)

#Diff Preasure reading
windgauge = cfg.get_device("windgauge")
windgauge.reset()
windgauge.initialize()
time.sleep(0.1)


rpm=0
dp=0.0
windgauge_spd=0.0
temp=0.0

#rpm_accuracny=0
running=1
def i2cThreadFunc():
    global rpm
    global dp
    global windgauge_spd
    global temp
    global running
    lastTime=time.time()
    lastCount=0
    while running==1:
        currentTime=time.time()
        currentCount=counter.get_count()
        rpm=(currentCount-lastCount)*60/signalPerRound/(currentTime-lastTime)
        #rpm_accurancy=60/signalPerRound/(currentTime-lastTime)
        lastTime=currentTime
        lastCount=currentCount
        dp, windgauge_spd = windgauge.get_dp_spd()
        temp = windgauge.get_temp()
        time.sleep(0.2)

thread = threading.Thread(target=i2cThreadFunc)
thread.start()

#logging
home =  os.path.expanduser("~")
path = home + "/TF-Aeroscale_logs/"
try:
    os.makedirs(path)
except OSError:
    print("")
else:
    print ("Successfully created the directory %s\n" % path)

log_name = ("TF_aeroscale_log_%.1f_%s.csv" % (angle,datetime.datetime.utcfromtimestamp(time.time()).isoformat()))
filepath = path + log_name
log_file = open(filepath, "w")
print ("Using logfile %s\n" % filepath)

log_file.write(  "           system_datetime;  freq ;  scale1;  scale2;   rpm;  dp[Pa];  spd[m/s];   T[C]; comp1;\n")
sys.stdout.write("           system_datetime;  freq ;  scale1;  scale2;   rpm;  dp[Pa];  spd[m/s];   T[C]; comp1;\n")
sys.stdout.flush() 

try:
    scale1.startConntinuousConversion(0)
    scale2.startConntinuousConversion(0)
    lastTime=time.time();
    w1d=False
    w2d=False

    angle_s=math.sin(angle*3.1415926/180.0)
    angle_c=math.cos(angle*3.1415926/180.0)
    while 1:
        if not w1d:
              w1d=not scale1.isBusy()
              if w1d:
                   w1 = scale1.measureWeight()
        if not w2d:
              w2d=not scale2.isBusy()
              if w2d:
                   w2 = scale2.measureWeight()

        if w1d and w2d:
              currentTime=time.time();
              ts = datetime.datetime.utcfromtimestamp(time.time()).isoformat()
              comp1=((2/3*w1)*16-w2*(5+15*angle_s))/(19+15*angle_c);
              sys.stdout.write("%s;  %04.1f;  %06.3f;  %06.3f;  %04.0f;  %06.1f;      %04.1f;   %04.1f; %06.3f\r" %(ts, 1/(currentTime-lastTime), w1,w2,rpm,dp,windgauge_spd,temp,comp1))
              log_file.write(  "%s;  %04.1f;  %06.3f;  %06.3f;  %04.0f;  %06.1f;      %04.1f;   %04.1f; %06.3f\n" %(ts, 1/(currentTime-lastTime), w1,w2,rpm,dp,windgauge_spd,temp,comp1))
              sys.stdout.flush()
              lastTime=currentTime
              w1d=False
              w2d=False

except KeyboardInterrupt:
    running=0
    log_file.close()
    thread.join()
    sys.exit(0)

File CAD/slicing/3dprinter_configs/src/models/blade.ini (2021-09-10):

bottom_solid_layers = 1
cooling = 0
disable_fan_first_layers = 3
extrusion_width = 0.45
fan_always_on = 0
fan_below_layer_time = 60
fill_density = 0%
first_layer_extrusion_width = 100%
first_layer_speed = 18
layer_height = 0.3
max_fan_speed = 0
min_shell_thickness = 0
min_top_bottom_shell_thickness = 0
only_retract_when_crossing_perimeters = 1
perimeter_extrusion_width = 0.45
perimeter_speed = 50
perimeters = 1
retract_before_travel = 3
retract_length = 0.5
retract_lift = 0
retract_restart_extra = 0.02
seam_position = rear
small_perimeter_speed = 15
solid_infill_below_area = 0
solid_infill_speed = 20
thin_walls = 0
top_infill_extrusion_width = 0
top_solid_infill_speed = 15
top_solid_layers = 0

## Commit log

2019-07-21 Moving of design files from TF-R1 repository.
    [888_5001.scad, 888_5002.scad, 888_5003.scad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]
2019-07-21 Modifying paths to enable making in new repository.
    [888_5001.scad, 888_5001.stl, 888_5002.scad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]
2019-07-21 logování do csv
    [weight.csv]
2019-07-24 přidání držáku na střechu
    [888_3007.scad, parameters.scad]
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2019-08-06 Removing unused libraries #2 Rendering models by make.
    [888_3007.scad, 888_3007.stl, 888_5001.stl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]
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2019-08-13 edit #2 uprava drzaku
    [888_3007.scad, parameters.scad]
2019-08-13 edit #2 uprava der na srouby
    [888_3007.scad]
2019-08-14 Vyrenderován díl držáku.
    [888_3007.stl]
2019-08-14 edit #3 888_5013.scad
    [888_5013.scad, parameters.scad]
2019-08-14 rendering models
    [888_5002.stl, 888_5006.stl, 888_5011.stl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]
2019-08-17 edit #2 úprava děr
    [888_3007.scad]
2019-09-09 uprava drzaku maleho rotoru, render
    [888_3007.stl, 888_5009.scad, 888_5009.stl]
2019-09-25 posunuto excentricky, díry na matky #5
    [888_3007.scad]
2019-09-26 Model rendering.
    [888_3007.stl, 888_5009.stl]
2019-09-26 Resized to maximum printable size.
    [888_3007.scad, 888_3007.stl]
2019-09-28 upraven držák tenzometru
    [888_5002.scad]
2020-03-12 Gcode manually generated.
    [888_3007.scad, 888_3007.stl, 888_5002.stl]
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2021-02-24 Add image of wiring for AC excitation. Add v2 develop software
2021-02-27 Base & mid base parts #9
    [888_3007.scad, 888_5003.scad, 888_5004.scad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]
2021-02-28 Tower part redesigned #9
    [888_5007.scad, 888_5008.scad, 888_5009.scad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]
2021-02-28 Drag sensor parts added #9
    [888_5010.scad, complete.scad]
2021-02-28 Fixed rotor joint bug #6
2021-02-28 888_5002 adding strength #9
    [888_5002.scad, complete.scad]
2021-03-03 Refactor AC excitation code littlebit, fix data conversion.
    [BRIDGEADC01.py]
2021-03-06 Fix of second channel
    [BRIDGEADC01.py]
2021-03-08 Drag sensor attached to 888_5007 #11
    [888_5007.scad, 888_5010.scad, complete.scad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]
2021-03-08 Mid base to base hinge redesign #12
    [888_5004.scad, complete.scad]
2021-03-08 Hinge design middle cylinder added #12
    [888_5005.scad, 888_5007.scad, 888_5010.scad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]
2021-03-08 888_5002 side strength adjustment #14
    [888_5002.scad]
2021-03-12 Tenzometer position change #11
    [888_5003.scad, complete.scad]
2021-03-12 Adding profile length for counterweight #13
    [complete.scad, parameters.scad]
2021-03-12 Base profile length change
    [complete.scad]
2021-03-15 Profile lengths changed
    [888_5007.scad, complete.scad, parameters.scad]
2021-03-17 Print polishing
    [888_5001.stl, 888_5002.stl, 888_5003.scad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]
2021-03-17 Hinges screw spacer fix
    [888_5010.scad, 888_5010.stl, 888_5011.scad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]
2021-03-17 Tenzometer attachment fix
    [888_5007.scad, complete.scad]
2021-03-17 Tenzometer attachment point redesign
    [888_5007.scad, complete.scad]
2021-03-17 Mid base hinges screw nut pockets added
    [888_5004.scad, 888_5006.scad, complete.scad]
2021-03-17 888_5004 wrong nut fix
    [888_5004.scad]
2021-03-17 STL update
    [888_5004.stl, 888_5006.stl, 888_5007.stl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]
2021-03-17 888_5002 screw pocket changed
    [888_5002.scad, 888_5002.stl, 888_5003_A.stl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]
2021-03-21 Adding temporary screw washer
    [888_5012.scad, 888_5012.stl]
2021-03-21 Recreate scale unit calibration because gain register cannot do large rescaling - calibration.py and measure.py are not update yet. https://ez.analog.com/data_converters/precision_adcs/w/documents/30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
2021-03-25 Construction hidden bug fixes
    [888_5002.stl, 888_5003_A.stl, 888_5003_B.stl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]
2021-03-25 888_3007 screws changed to M6
    [888_3007.scad]
2021-03-25 Print plates added
    [888_3007.scad, 888_5001.scad, 888_5002.scad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]
2021-03-27 Cable holders added
    [888_5013.scad, 888_5013.stl]
2021-03-28 update calibration and measire to python 3 a nd current scale class interface
2021-04-02 Fix calibration save precision issue
2021-04-24 TF-G2 adapter added
    [TF_G2_rotor_adapter.scad, TF_G2_rotor_adapter.stl]
2021-04-24 Rotor clearance adjustment
    [TF_G2_rotor_adapter.scad, TF_G2_rotor_adapter.stl]
2021-04-24 Rotor joint thickness
    [TF_G2_rotor_adapter.scad, TF_G2_rotor_adapter.stl]
2021-04-24 TF_G2_rotor_adapter print_plate added
    [TF_G2_rotor_adapter.scad, TF_G2_rotor_adapter.stl]
2021-04-29 Wire space fix
    [TF_G2_rotor_adapter.scad, TF_G2_rotor_adapter.stl]
2021-05-01 Rotor strength improved #22
    [TF_G2_rotor_adapter.scad, TF_G2_rotor_adapter.stl]
2021-05-04 Add continuous measuring of ADC bridge and sample of this.
2021-05-04 Add bastled skript for parallel measurement of airspeed and RPM of rotor. It is based on mlab samples, not fully adjusted for this measurement now
2021-05-05 Rotor joint module fix
2021-05-05 Basic x axis calibration device added #16
    [888_1001.scad, 888_1001.stl, 888_1002.scad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]
2021-05-07 888_1001 adding reinforcement #16
    [888_1001.scad, 888_1001.stl]
2021-05-07 Box attachment parts added #18
    [888_5013.scad, 888_5014.scad, 888_5014_Back.scad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]
2021-05-08 888_5014 corner space fix #18
    [888_5014.scad, 888_5014_Back.stl]
2021-06-07 Bug fix rotor_scale nut hole
2021-06-26 Adding processor3D connection
    [888_1001.scad, 888_1001.stl, 888_1002.scad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]
2021-06-26 changing to casesensitive repo
    [888_1001.scad, 888_1002.scad, 888_1003.scad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]
2021-06-26 removing old cad folder
    [888_1001.scad, 888_1002.scad, 888_1003.scad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]
2021-06-26 Automatic commit from workflow
    [888_1001.amf, 888_1002.amf, 888_1003.amf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]
2021-06-28 888_5003 printing change
    [888_5003.scad, 888_5003_A.scad, 888_5003_B.scad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]
2021-07-30 Top triangle new backplate && anglemeter
    [888_5007.scad, 888_5008.scad, 888_5015.scad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]
2021-08-15 Add expermiental motor on rotor
    [888_4008.scad, 888_7001.scad, TF_G2_rotor_adapter_with motor.scad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]
2021-08-17 888_5007 strength improvement
    [888_5007.scad]
2021-08-17 add motor wheeel
    [888_7002.scad, TF_G2_rotor_adapter_with motor.scad]
2021-08-18 888_5007 edge removed
    [888_5007.scad]
2021-08-24 888_5007 manifold error fix
    [888_5007.scad]
2021-08-28 Fix bad height of motor holder.
    [TF_G2_rotor_adapter_with motor.scad]
2021-09-01 Fix missing hole for bearing.
    [888_5007.scad]
2021-09-10 Add scripts for one and 2 rpi-spi weight without i2c stuff
2021-09-10 fix annoing queston from measurement script
    [2_scale_measure_spidev_rpm_dp.py]
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2022-04-10 try to improve motor prerortartor for rotor
    [TF_G2_rotor_adapter_with motor.scad]
2022-04-10 missing files
    [TF-G2-rotor-neck.scad, TF_G2_neck_test.scad, rotor_pulley.scad]
